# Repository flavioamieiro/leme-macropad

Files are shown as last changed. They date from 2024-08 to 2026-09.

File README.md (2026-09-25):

## Leme macropad

This is a macropad based on the RP2040 microcontroller meant to run QMK.

It currently is a handwired macropad using a raspberry Pi pico

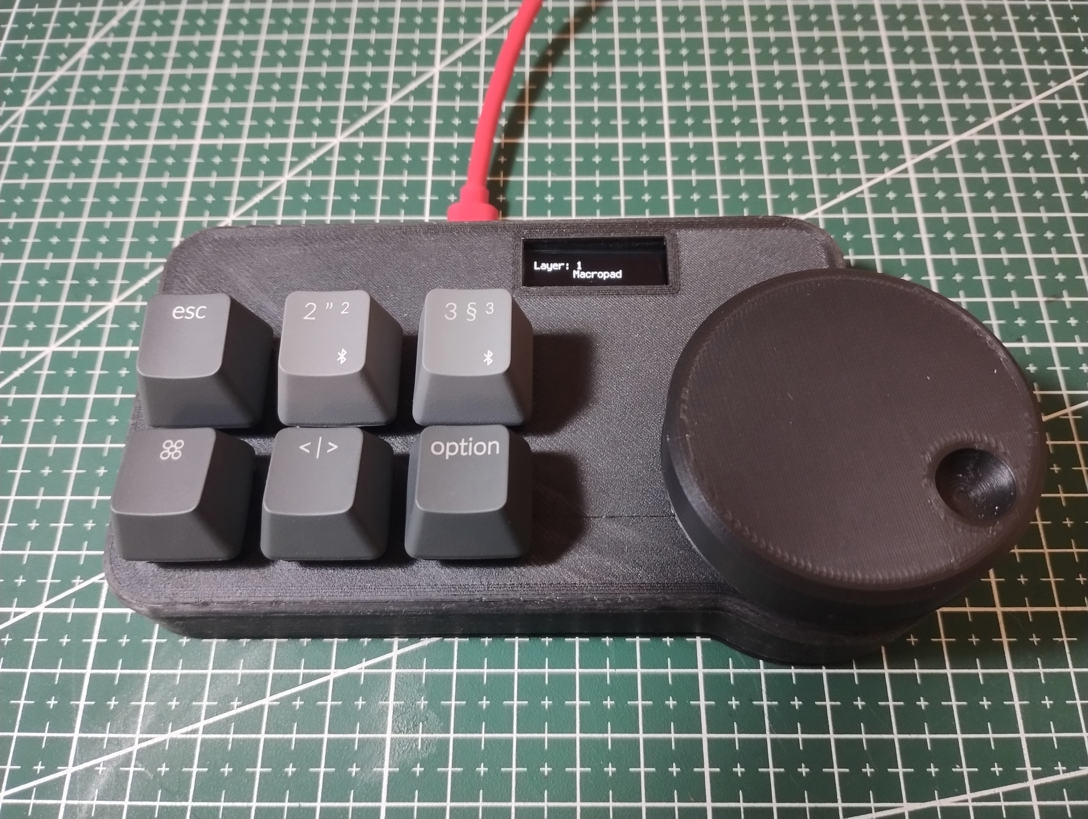
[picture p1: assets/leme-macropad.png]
leme macropad


The [README in the software directory](software/README.md) explains how to install QMK on a raspberry pi pico to support it.

The [leme_macropad](leme_macropad/) directory contains a first revision for custom hardware for it (which, unfortunately, currently doesn't work).

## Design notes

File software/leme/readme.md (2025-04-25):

# leme

leme

A simple macropad with six keys, a rotary encoder and a small screen

* Keyboard Maintainer: [Flávio Amieiro](https://github.com/flavioamieiro)
* Hardware Supported: Custom PCB released as open hardware
* Hardware Availability: https://github.com/flavioamieiro/leme-macropad

Make example for this keyboard (after setting up your build environment):

    make leme:default

Flashing example for this keyboard:

    make leme:default:flash

See the [build environment setup](https://docs.qmk.fm/#/getting_started_build_tools) and the [make instructions](https://docs.qmk.fm/#/getting_started_make_guide) for more information. Brand new to QMK? Start with our [Complete Newbs Guide](https://docs.qmk.fm/#/newbs).

## Bootloader

To enter the bootloader , hold down the top left key while you plug in the macropad.

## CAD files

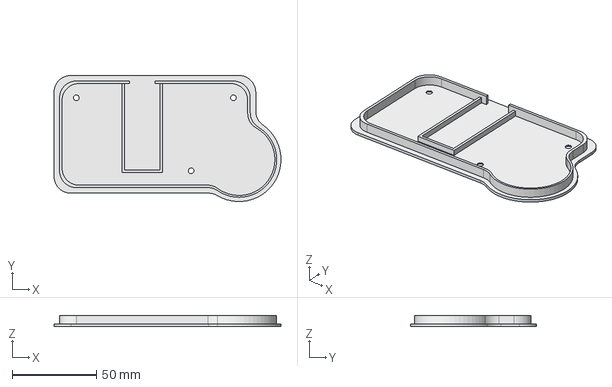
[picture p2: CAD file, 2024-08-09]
case/leme.FCStd
135.0 x 75.0 x 6.50 mm

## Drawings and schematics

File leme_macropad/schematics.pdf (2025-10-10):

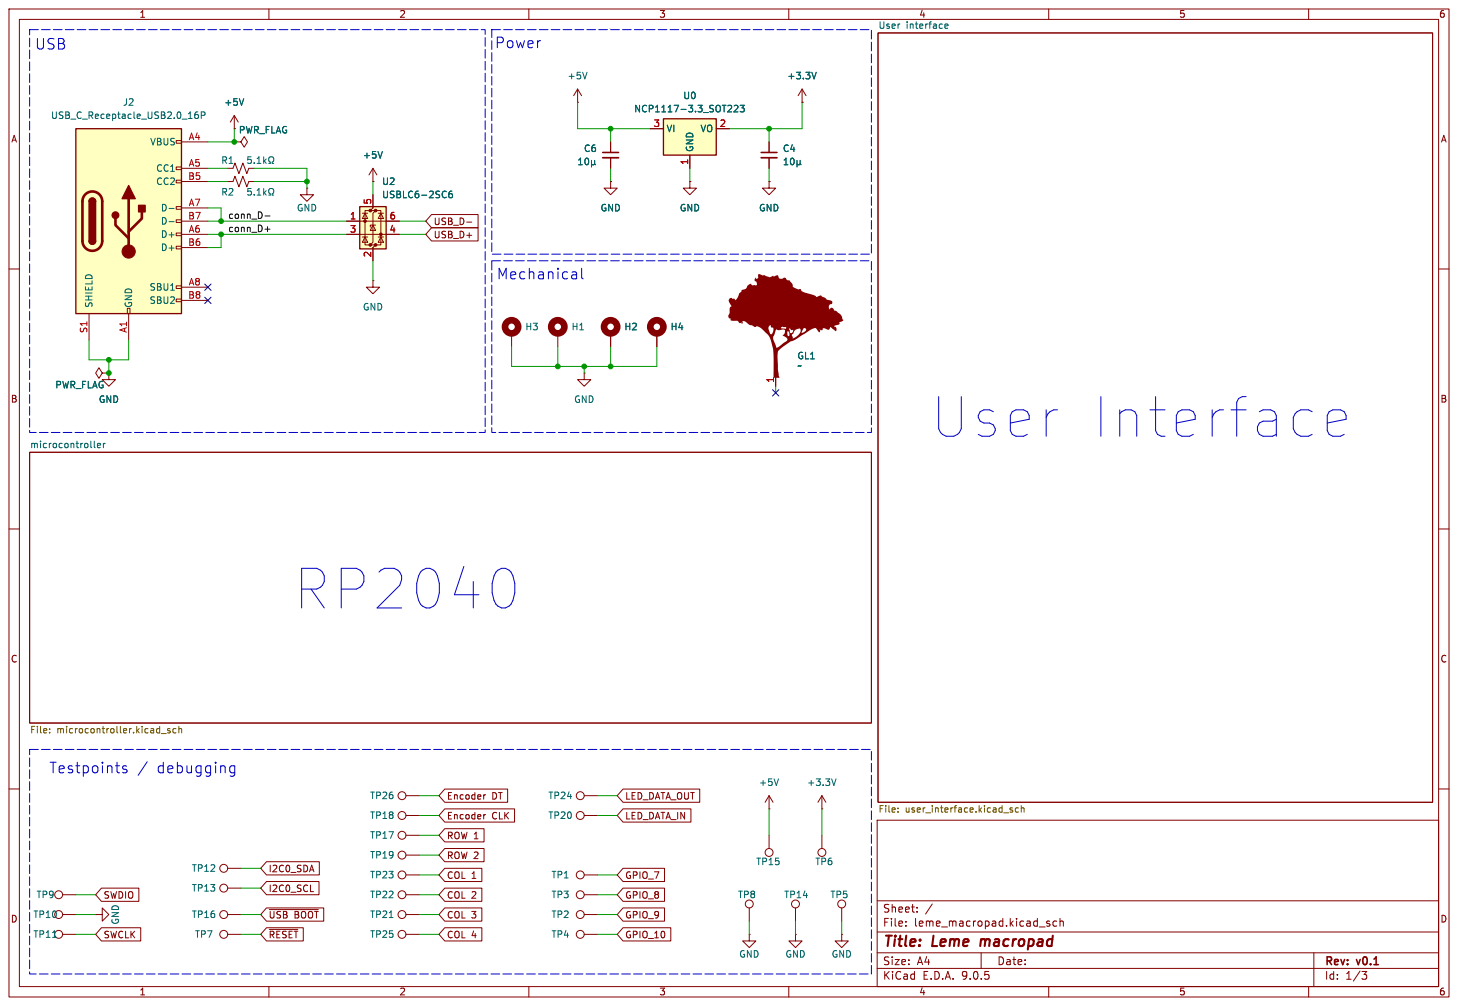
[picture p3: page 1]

File: leme_macropad.kicad_sch Sheet: / microcontroller File: microcontroller.kicad_sch

Id: 1/3 Title: Leme macropad

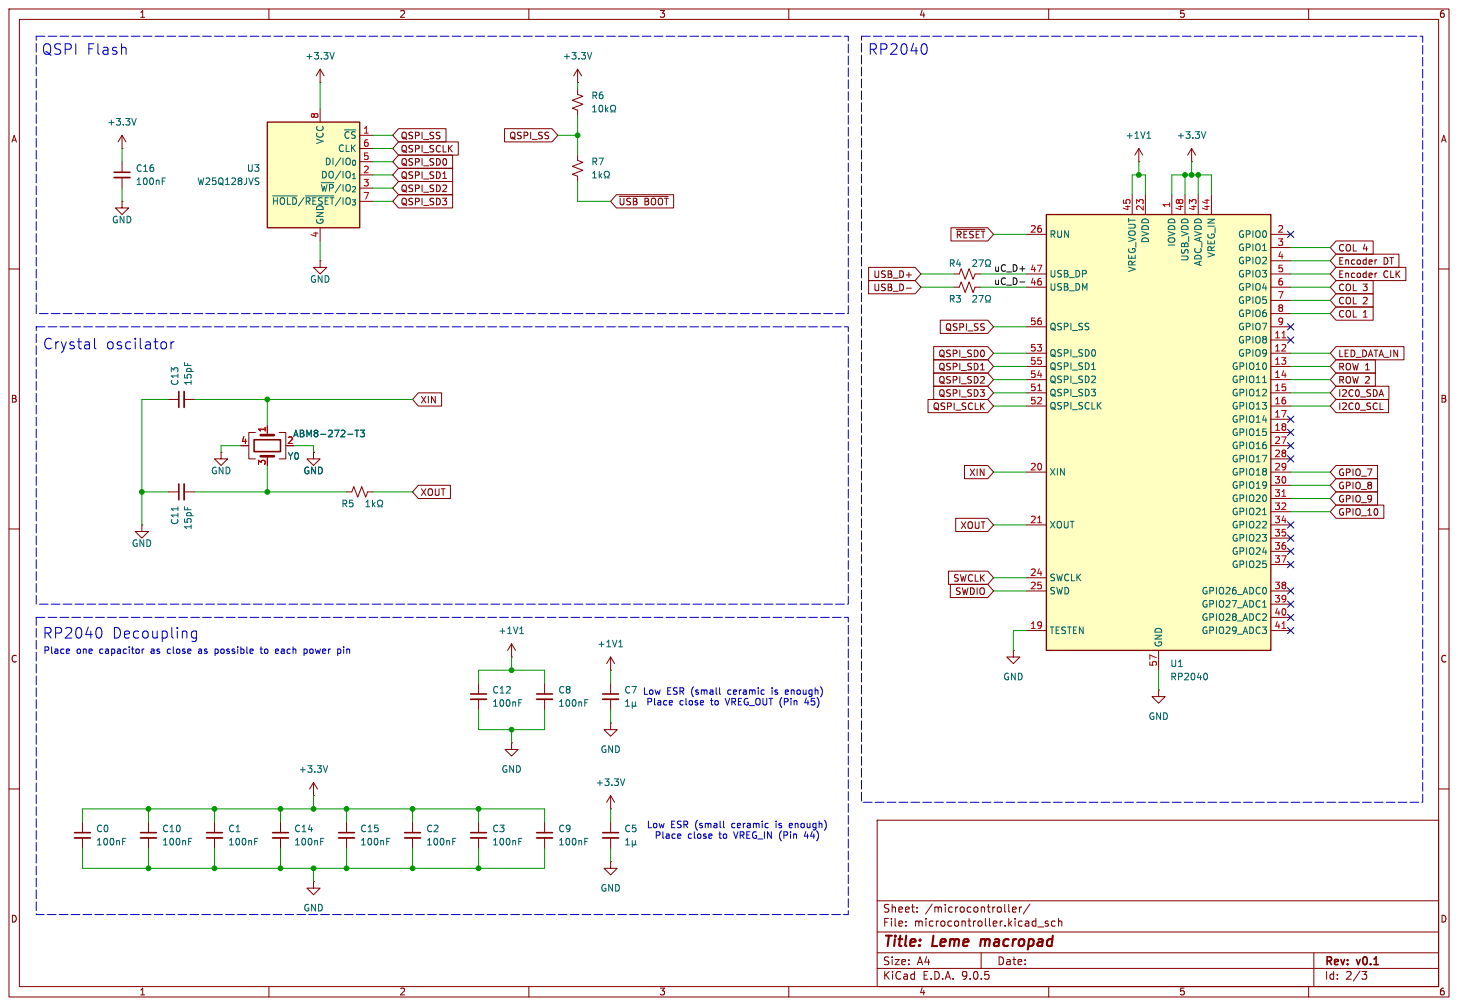
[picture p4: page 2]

File: microcontroller.kicad_sch Sheet: /microcontroller/
Id: 2/3 Title: Leme macropad

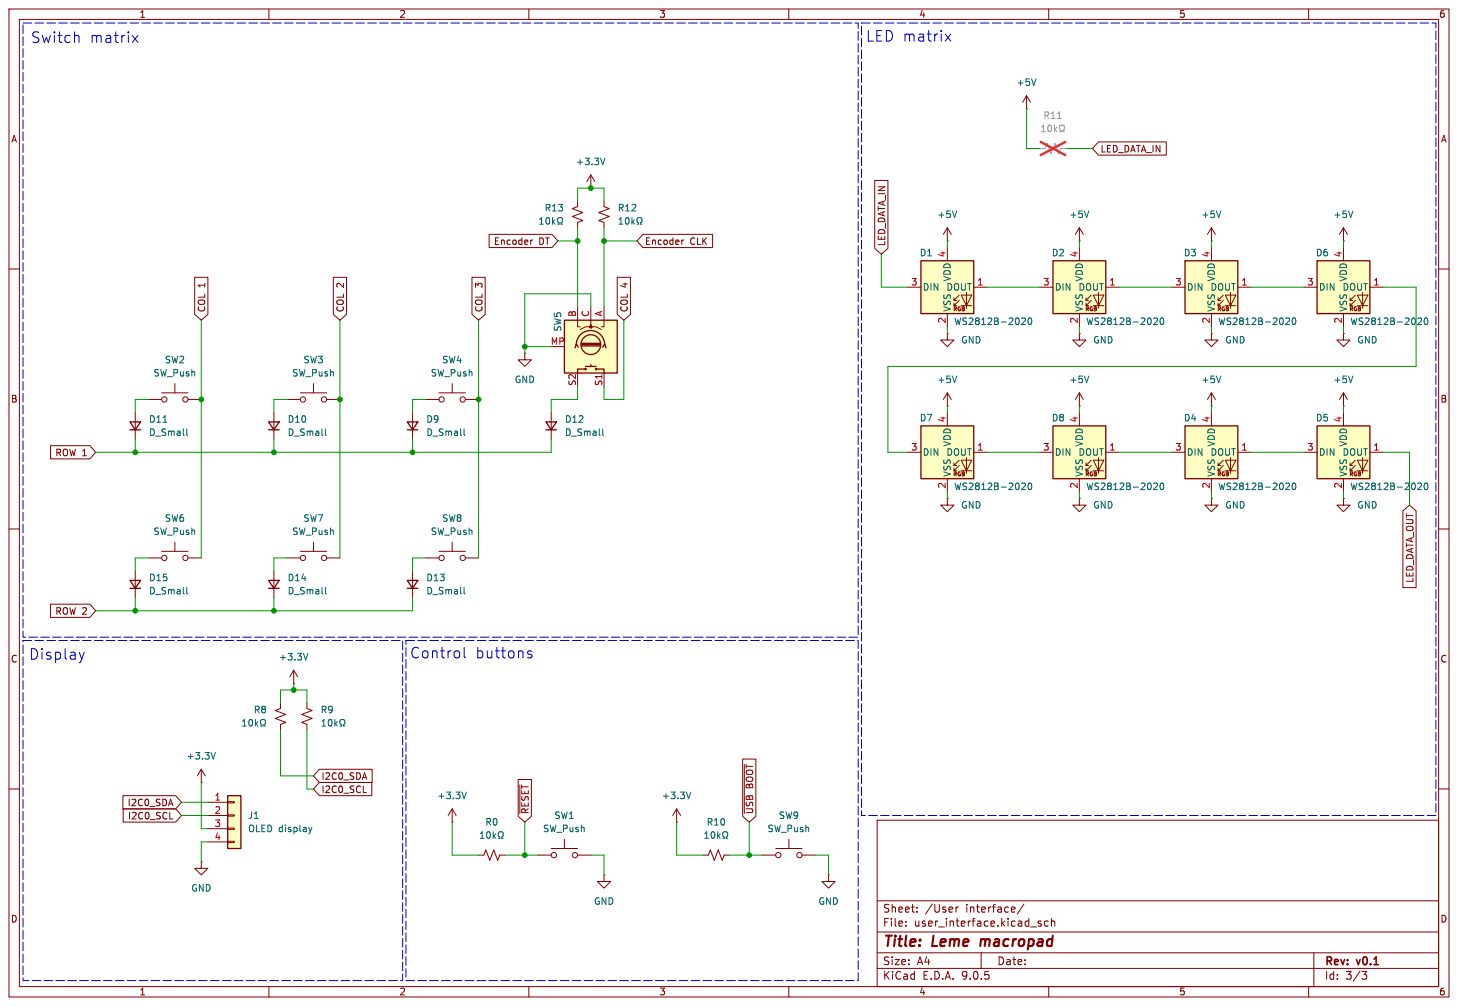
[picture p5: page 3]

File: user_interface.kicad_sch Sheet: /User interface/
Id: 3/3 Title: Leme macropad

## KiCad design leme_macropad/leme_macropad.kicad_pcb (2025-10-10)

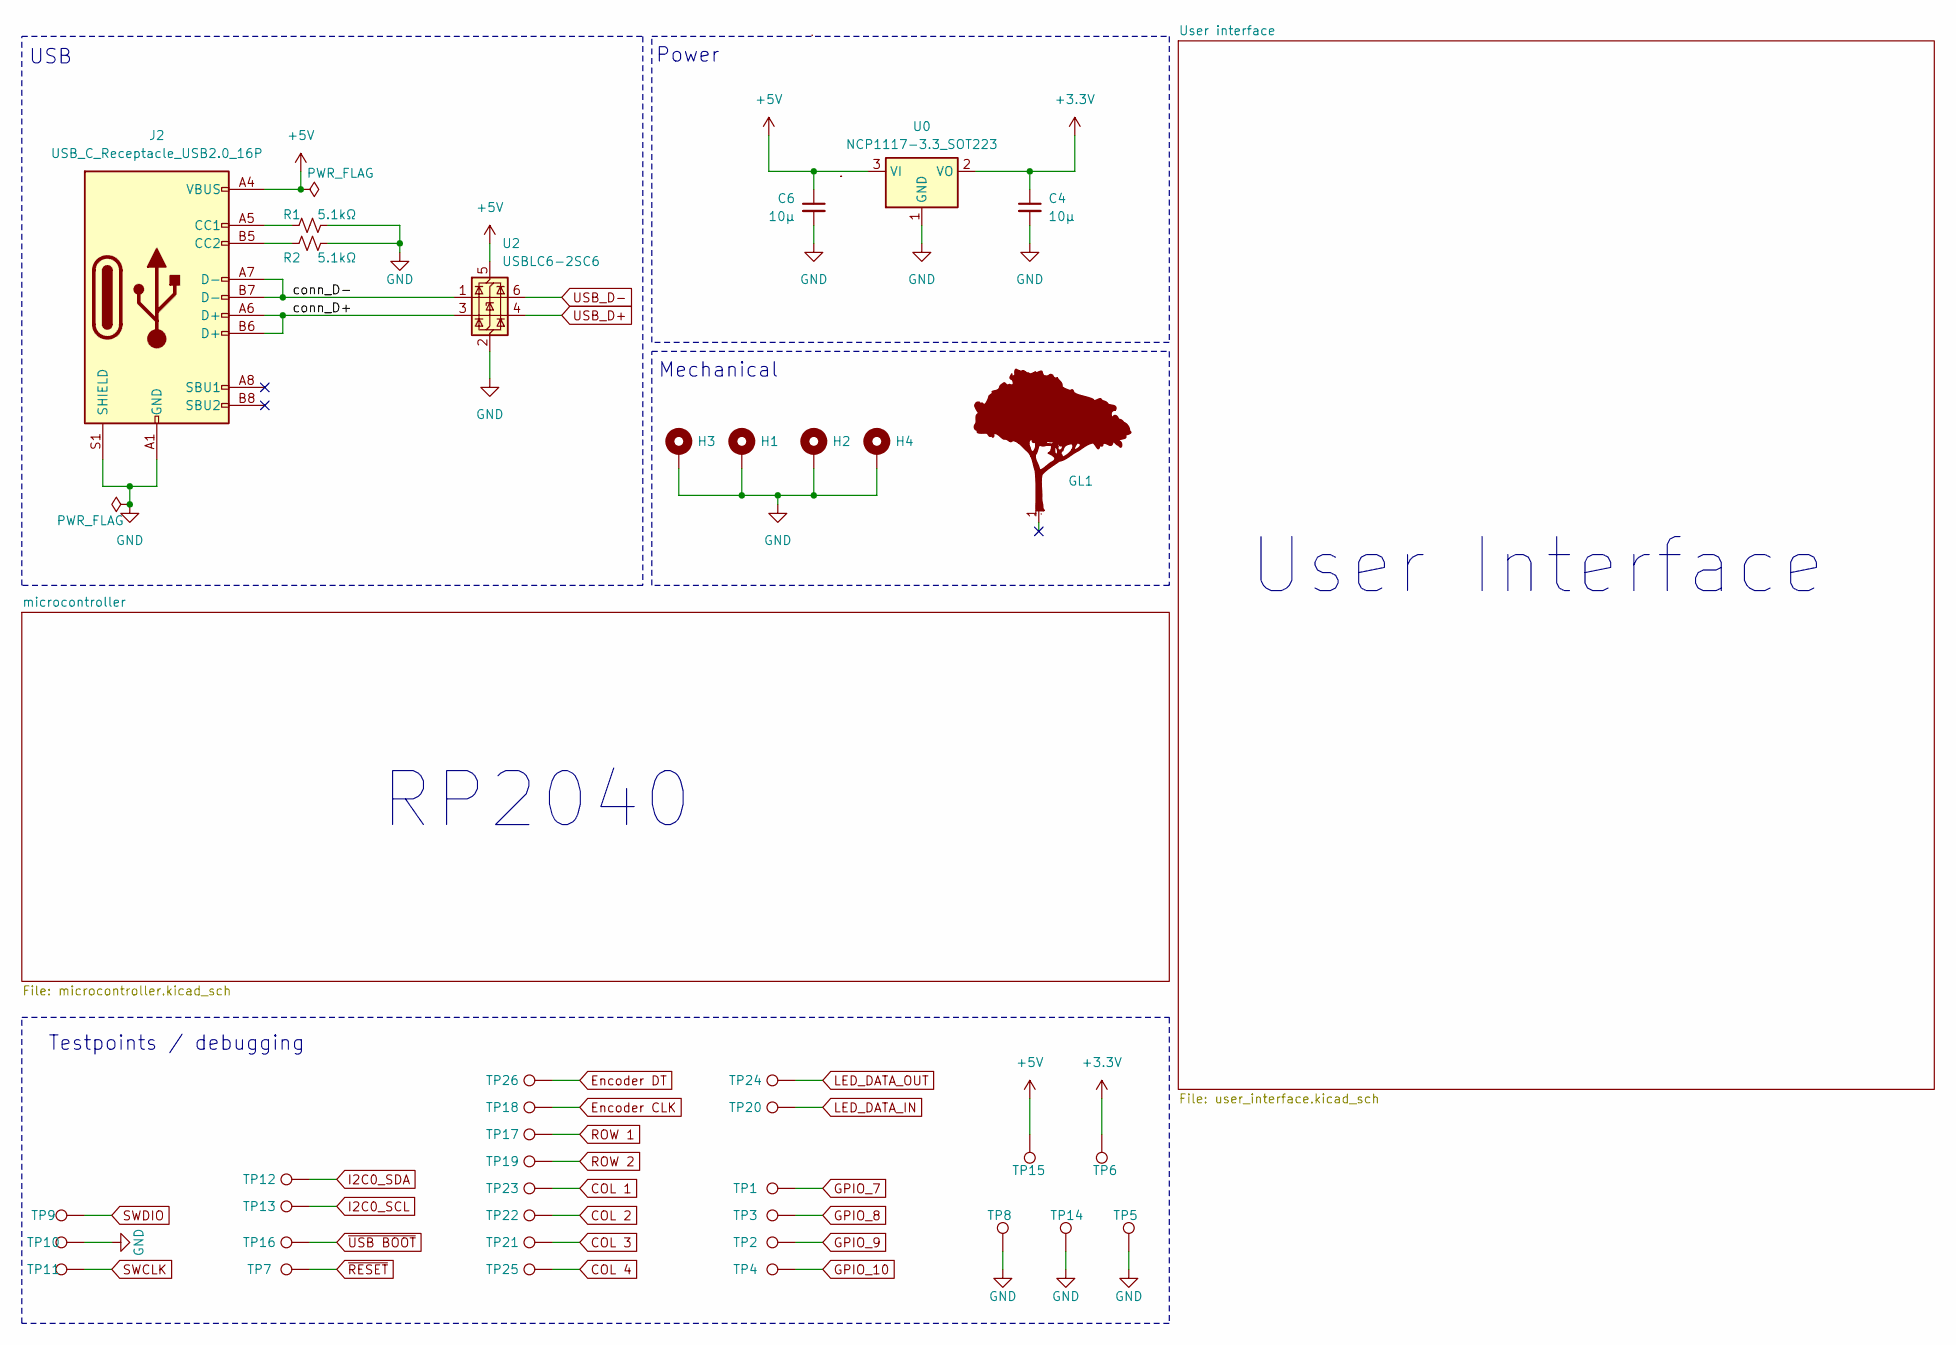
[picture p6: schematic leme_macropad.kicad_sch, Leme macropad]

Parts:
C4, C6: 10μ; C_0402_1005Metric_Pad0.74x0.62mm_HandSolder
GL1: ipe_logo
H1, H2, H3, H4: MountingHole_Pad; MountingHole_2.2mm_M2_Pad
J2: USB_C_Receptacle_USB2.0_16P; USB_C_Receptacle_GCT_USB4105-xx-A_16P_TopMnt_Horizontal
R1, R2: 5.1kΩ; R_0402_1005Metric_Pad0.72x0.64mm_HandSolder
TP1, TP2, TP3, TP4, TP5, TP6, TP7, TP8, TP9, TP10, TP11, TP12, TP13, TP14, TP15, TP16, TP17, TP18, TP19, TP20, TP21, TP22, TP23, TP24, TP25, TP26: TestPoint; TestPoint_Pad_D1.0mm
U0: NCP1117-3.3_SOT223; SOT-223-3_TabPin2
U2: USBLC6-2SC6; SOT-23-6

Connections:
+3.3V: C4.1, TP6.1, U0.2 (VO); also elsewhere on the board
+5V: C6.1, J2.A4 (VBUS), J2.A9 (VBUS), J2.B4 (VBUS), J2.B9 (VBUS), TP15.1, U0.3 (VI), U2.5 (VBUS); also elsewhere on the board
/conn_D+: J2.A6 (D+), J2.B6 (D+), U2.3 (I/O2)
/conn_D-: J2.A7 (D-), J2.B7 (D-), U2.1 (I/O1)
COL 1: TP23.1; also elsewhere on the board
COL 2: TP22.1; also elsewhere on the board
COL 3: TP21.1; also elsewhere on the board
COL 4: TP25.1; also elsewhere on the board
Encoder CLK: TP18.1; also elsewhere on the board
Encoder DT: TP26.1; also elsewhere on the board
GND: C4.2, C6.2, H1.1, H2.1, H3.1, H4.1, J2.A1 (GND), J2.A12 (GND), J2.B1 (GND), J2.B12 (GND), J2.S1 (SHIELD), R1.2, R2.2, TP5.1, TP8.1, TP10.1, TP14.1, U0.1 (GND), U2.2 (GND); also elsewhere on the board
GPIO_7: TP1.1; also elsewhere on the board
GPIO_8: TP3.1; also elsewhere on the board
GPIO_9: TP2.1; also elsewhere on the board
GPIO_10: TP4.1; also elsewhere on the board
I2C0_SCL: TP13.1; also elsewhere on the board
I2C0_SDA: TP12.1; also elsewhere on the board
LED_DATA_IN: TP20.1; also elsewhere on the board
LED_DATA_OUT: TP24.1; also elsewhere on the board
unnamed: J2.A5 (CC1), R1.1
unnamed: J2.B5 (CC2), R2.1
ROW 1: TP17.1; also elsewhere on the board
ROW 2: TP19.1; also elsewhere on the board
SWCLK: TP11.1; also elsewhere on the board
SWDIO: TP9.1; also elsewhere on the board
USB_D+: U2.4 (I/O2); also elsewhere on the board
USB_D-: U2.6 (I/O1); also elsewhere on the board
~RESET: TP7.1; also elsewhere on the board
~USB BOOT: TP16.1; also elsewhere on the board

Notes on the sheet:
Mechanical
User Interface
USB
RP2040
Testpoints / debugging
Power

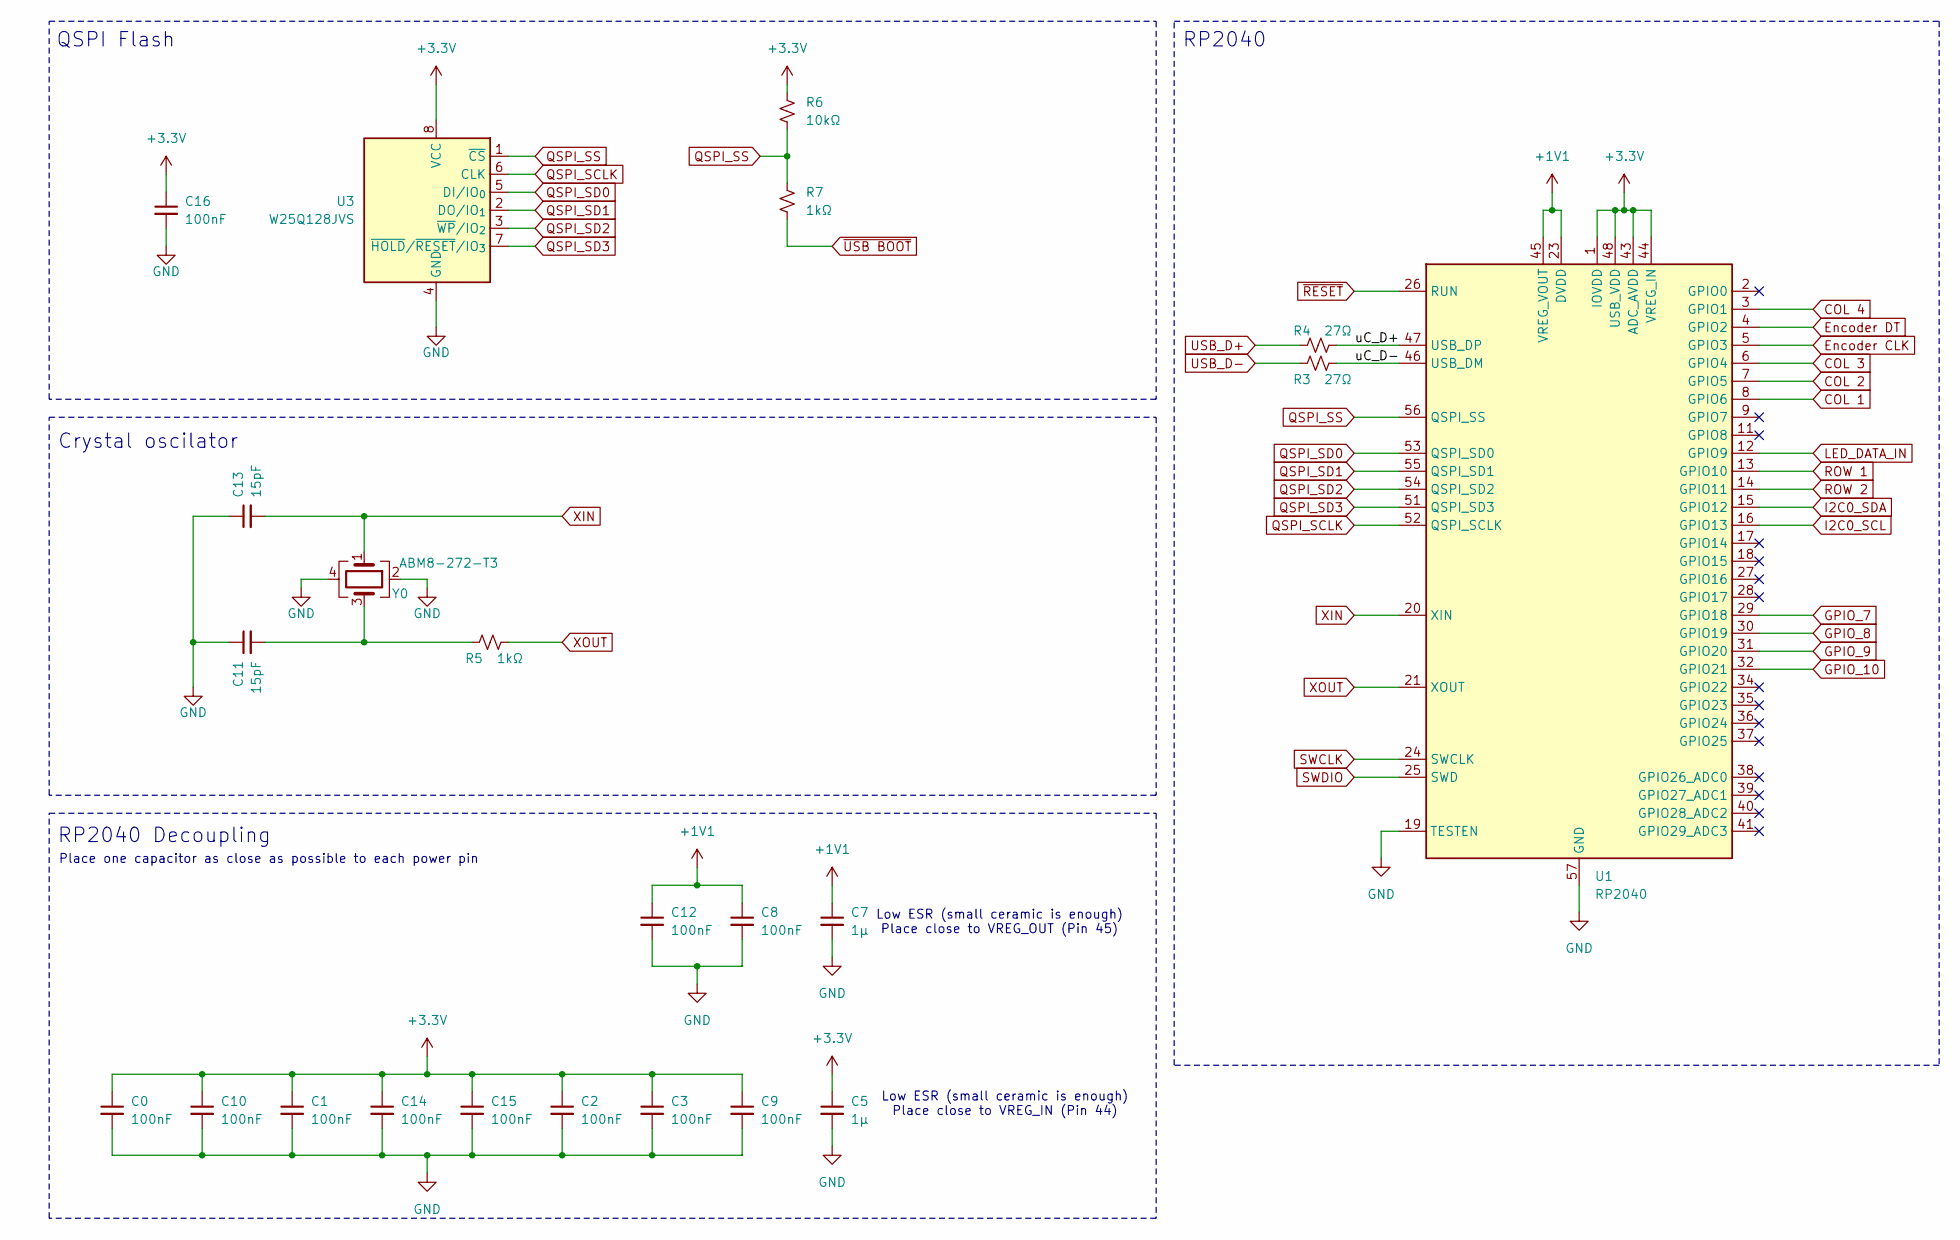
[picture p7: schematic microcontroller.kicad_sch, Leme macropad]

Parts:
C0, C1, C2, C3, C8, C9, C10, C12, C14, C15, C16: 100nF; C_0402_1005Metric_Pad0.74x0.62mm_HandSolder
C5, C7: 1μ; C_0402_1005Metric_Pad0.74x0.62mm_HandSolder
C11, C13: 15pF; C_0402_1005Metric_Pad0.74x0.62mm_HandSolder
R3, R4: 27Ω; R_0402_1005Metric_Pad0.72x0.64mm_HandSolder
R5, R7: 1kΩ; R_0402_1005Metric_Pad0.72x0.64mm_HandSolder
R6: 10kΩ; R_0402_1005Metric_Pad0.72x0.64mm_HandSolder
U1: RP2040; QFN-56-1EP_7x7mm_P0.4mm_EP3.2x3.2mm
U3: W25Q128JVS; SOIC-8_5.3x5.3mm_P1.27mm
Y0: ABM8-272-T3; Crystal_SMD_3225-4Pin_3.2x2.5mm

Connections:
+1V1: C7.1, C8.1, C12.1, U1.23 (DVDD), U1.45 (VREG_VOUT), U1.50 (DVDD)
+3.3V: C0.1, C1.1, C2.1, C3.1, C5.1, C9.1, C10.1, C14.1, C15.1, C16.1, R6.2, U1.1 (IOVDD), U1.10 (IOVDD), U1.22 (IOVDD), U1.33 (IOVDD), U1.42 (IOVDD), U1.43 (ADC_AVDD), U1.44 (VREG_IN), U1.48 (USB_VDD), U1.49 (IOVDD), U3.8 (VCC); also elsewhere on the board
/microcontroller/uC_D+: R4.2, U1.47 (USB_DP)
/microcontroller/uC_D-: R3.2, U1.46 (USB_DM)
COL 1: U1.8 (GPIO6); also elsewhere on the board
COL 2: U1.7 (GPIO5); also elsewhere on the board
COL 3: U1.6 (GPIO4); also elsewhere on the board
COL 4: U1.3 (GPIO1); also elsewhere on the board
Encoder CLK: U1.5 (GPIO3); also elsewhere on the board
Encoder DT: U1.4 (GPIO2); also elsewhere on the board
GND: C0.2, C1.2, C2.2, C3.2, C5.2, C7.2, C8.2, C9.2, C10.2, C11.1, C12.2, C13.1, C14.2, C15.2, C16.2, U1.19 (TESTEN), U1.57 (GND), U3.4 (GND), Y0.2, Y0.4; also elsewhere on the board
GPIO_7: U1.29 (GPIO18); also elsewhere on the board
GPIO_8: U1.30 (GPIO19); also elsewhere on the board
GPIO_9: U1.31 (GPIO20); also elsewhere on the board
GPIO_10: U1.32 (GPIO21); also elsewhere on the board
I2C0_SCL: U1.16 (GPIO13); also elsewhere on the board
I2C0_SDA: U1.15 (GPIO12); also elsewhere on the board
LED_DATA_IN: U1.12 (GPIO9); also elsewhere on the board
unnamed: C11.2, R5.1, Y0.3
QSPI_SCLK: U1.52 (QSPI_SCLK), U3.6 (CLK)
QSPI_SD0: U1.53 (QSPI_SD0), U3.5 (DI/IO_{0})
QSPI_SD1: U1.55 (QSPI_SD1), U3.2 (DO/IO_{1})
QSPI_SD2: U1.54 (QSPI_SD2), U3.3 (~WP/IO_{2})
QSPI_SD3: U1.51 (QSPI_SD3), U3.7 (~HOLD/~RESET/IO_{3})
QSPI_SS: R6.1, R7.2, U1.56 (QSPI_SS), U3.1 (~CS)
ROW 1: U1.13 (GPIO10); also elsewhere on the board
ROW 2: U1.14 (GPIO11); also elsewhere on the board
SWCLK: U1.24 (SWCLK); also elsewhere on the board
SWDIO: U1.25 (SWD); also elsewhere on the board
USB_D+: R4.1; also elsewhere on the board
USB_D-: R3.1; also elsewhere on the board
XIN: C13.2, U1.20 (XIN), Y0.1
XOUT: R5.2, U1.21 (XOUT)
~RESET: U1.26 (RUN); also elsewhere on the board
~USB BOOT: R7.1; also elsewhere on the board

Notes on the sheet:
RP2040 Decoupling
Place one capacitor as close as possible to each power pin
QSPI Flash
RP2040
Low ESR (small ceramic is enough) Place close to VREG_OUT (Pin 45)
Low ESR (small ceramic is enough) Place close to VREG_IN (Pin 44)
Crystal oscilator

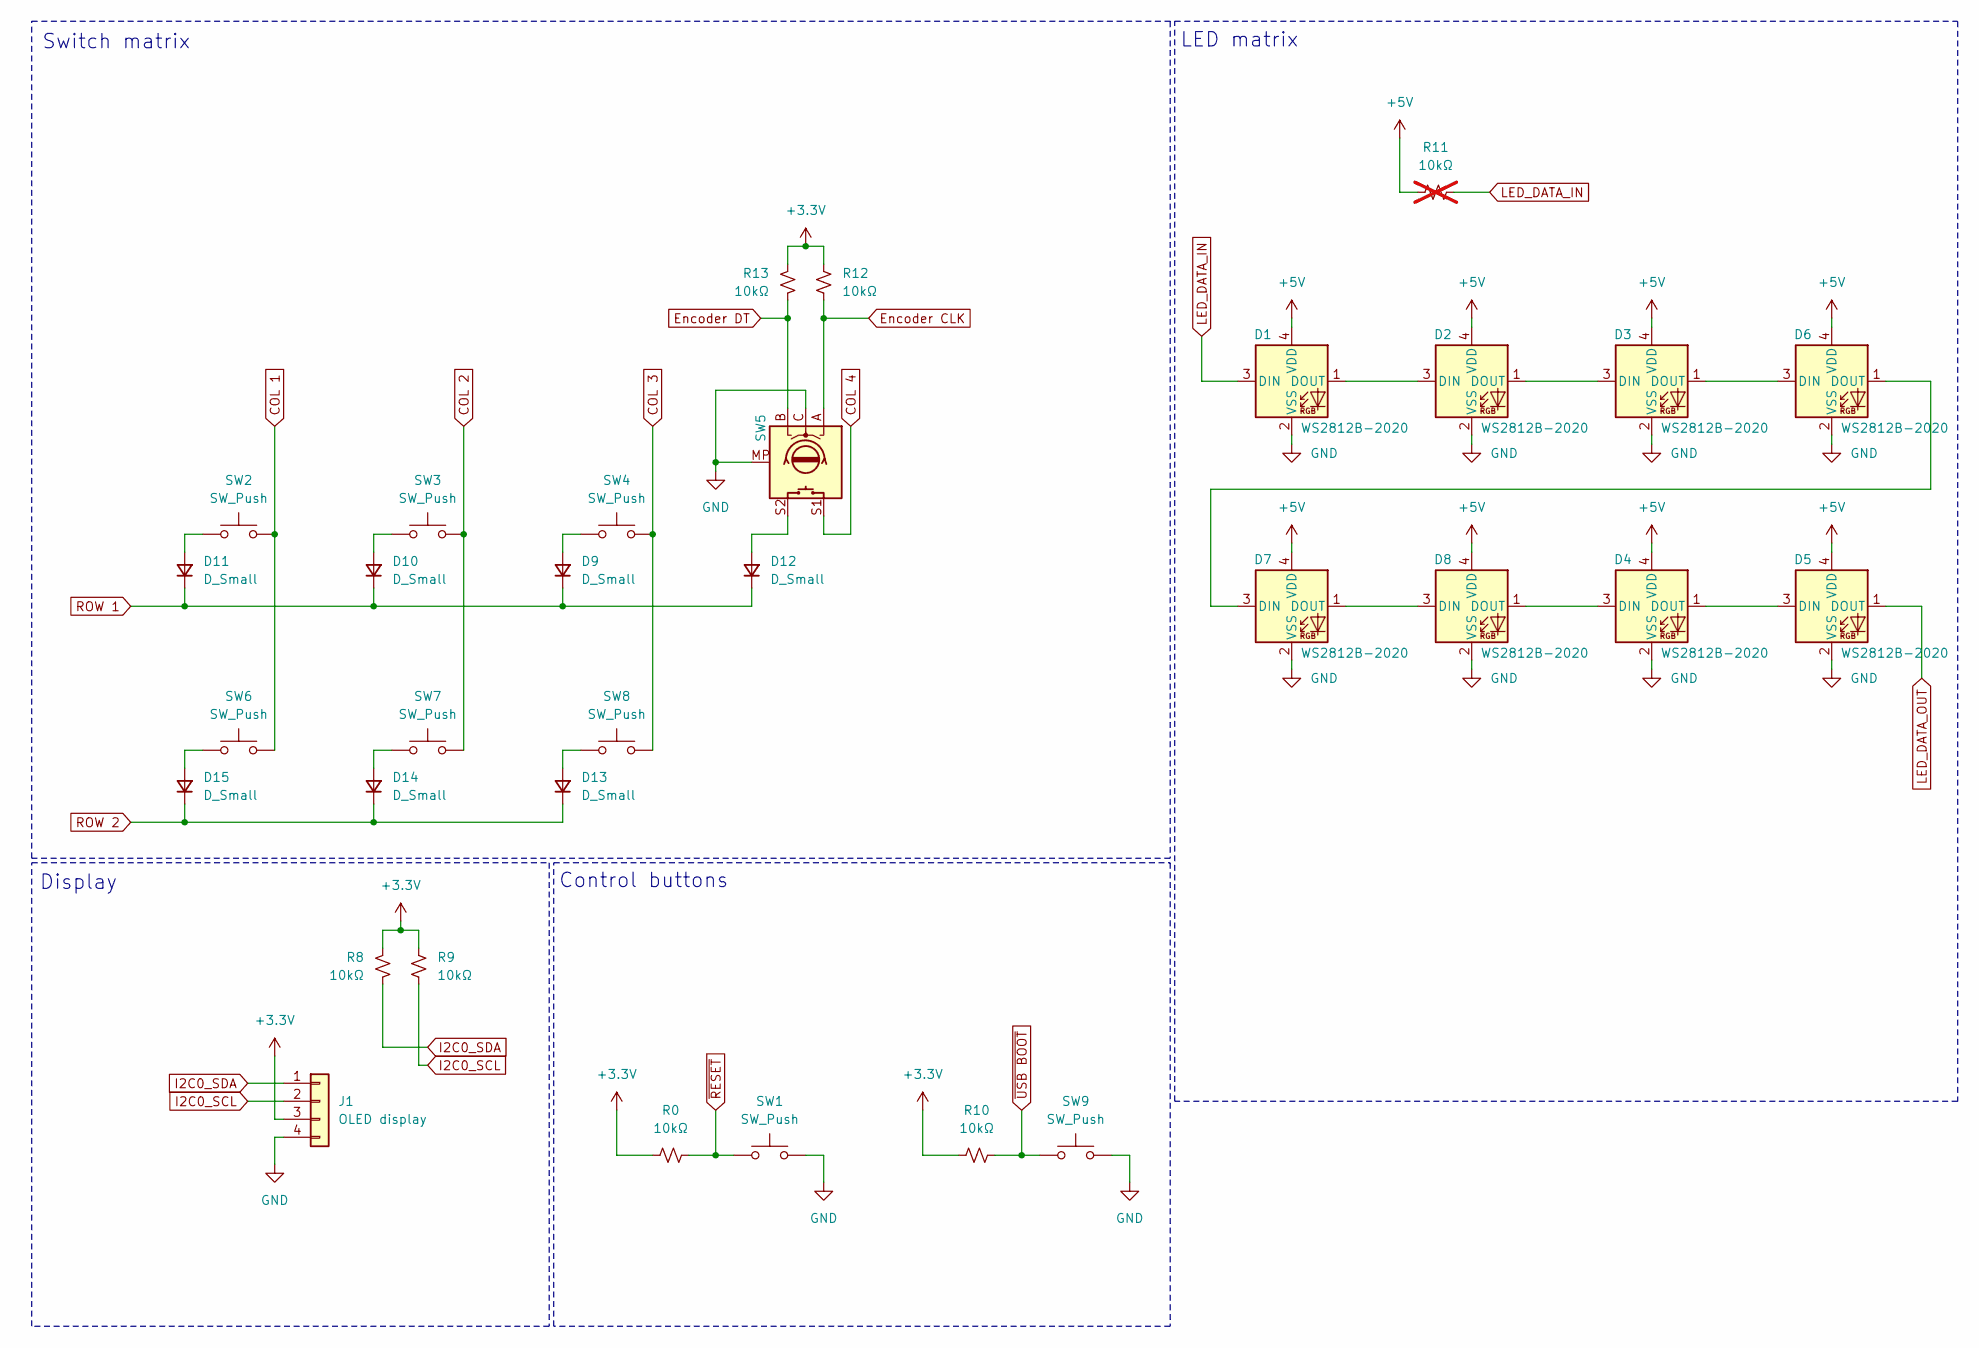
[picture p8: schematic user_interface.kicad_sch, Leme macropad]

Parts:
D1, D2, D3, D4, D5, D6, D7, D8: WS2812B-2020; LED_WS2812B-2020_PLCC4_2.0x2.0mm
D9, D10, D11, D12, D13, D14, D15: D_Small; D_SOD-123
J1: OLED display; PinHeader_1x04_P2.54mm_Vertical
R0, R8, R9, R10, R12, R13: 10kΩ; R_0402_1005Metric_Pad0.72x0.64mm_HandSolder
R11: 10kΩ; R_0402_1005Metric_Pad0.72x0.64mm_HandSolder; not fitted
SW1, SW9: SW_Push; CK_PTS636_SK43_SMTR_LFS
SW2, SW3, SW4, SW6, SW7, SW8: SW_Push; SW_Hotswap_Kailh_Choc_V1V2_1.00u
SW5: RotaryEncoder_Switch; RotaryEncoder_Alps_EC11E-Switch_Vertical_H20mm

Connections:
+3.3V: J1.3, R0.1, R8.2, R9.2, R10.1, R12.2, R13.2; also elsewhere on the board
+5V: D1.4 (VDD), D2.4 (VDD), D3.4 (VDD), D4.4 (VDD), D5.4 (VDD), D6.4 (VDD), D7.4 (VDD), D8.4 (VDD), R11.1; also elsewhere on the board
COL 1: SW2.2, SW6.2; also elsewhere on the board
COL 2: SW3.2, SW7.2; also elsewhere on the board
COL 3: SW4.2, SW8.2; also elsewhere on the board
COL 4: SW5.S1; also elsewhere on the board
Encoder CLK: R12.1, SW5.A; also elsewhere on the board
Encoder DT: R13.1, SW5.B; also elsewhere on the board
GND: D1.2 (VSS), D2.2 (VSS), D3.2 (VSS), D4.2 (VSS), D5.2 (VSS), D6.2 (VSS), D7.2 (VSS), D8.2 (VSS), J1.4, SW1.2, SW5.C, SW5.MP, SW9.2; also elsewhere on the board
I2C0_SCL: J1.2, R9.1; also elsewhere on the board
I2C0_SDA: J1.1, R8.1; also elsewhere on the board
LED_DATA_IN: D1.3 (DIN), R11.2; also elsewhere on the board
LED_DATA_OUT: D5.1 (DOUT); also elsewhere on the board
unnamed: D1.1 (DOUT), D2.3 (DIN)
unnamed: D2.1 (DOUT), D3.3 (DIN)
unnamed: D3.1 (DOUT), D6.3 (DIN)
unnamed: D4.3 (DIN), D8.1 (DOUT)
unnamed: D4.1 (DOUT), D5.3 (DIN)
unnamed: D6.1 (DOUT), D7.3 (DIN)
unnamed: D7.1 (DOUT), D8.3 (DIN)
unnamed: D9.2 (A), SW4.1
unnamed: D10.2 (A), SW3.1
unnamed: D11.2 (A), SW2.1
unnamed: D12.2 (A), SW5.S2
unnamed: D13.2 (A), SW8.1
unnamed: D14.2 (A), SW7.1
unnamed: D15.2 (A), SW6.1
ROW 1: D9.1 (K), D10.1 (K), D11.1 (K), D12.1 (K); also elsewhere on the board
ROW 2: D13.1 (K), D14.1 (K), D15.1 (K); also elsewhere on the board
~RESET: R0.2, SW1.1; also elsewhere on the board
~USB BOOT: R10.2, SW9.1; also elsewhere on the board

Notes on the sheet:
Control buttons
Switch matrix
LED matrix
Display

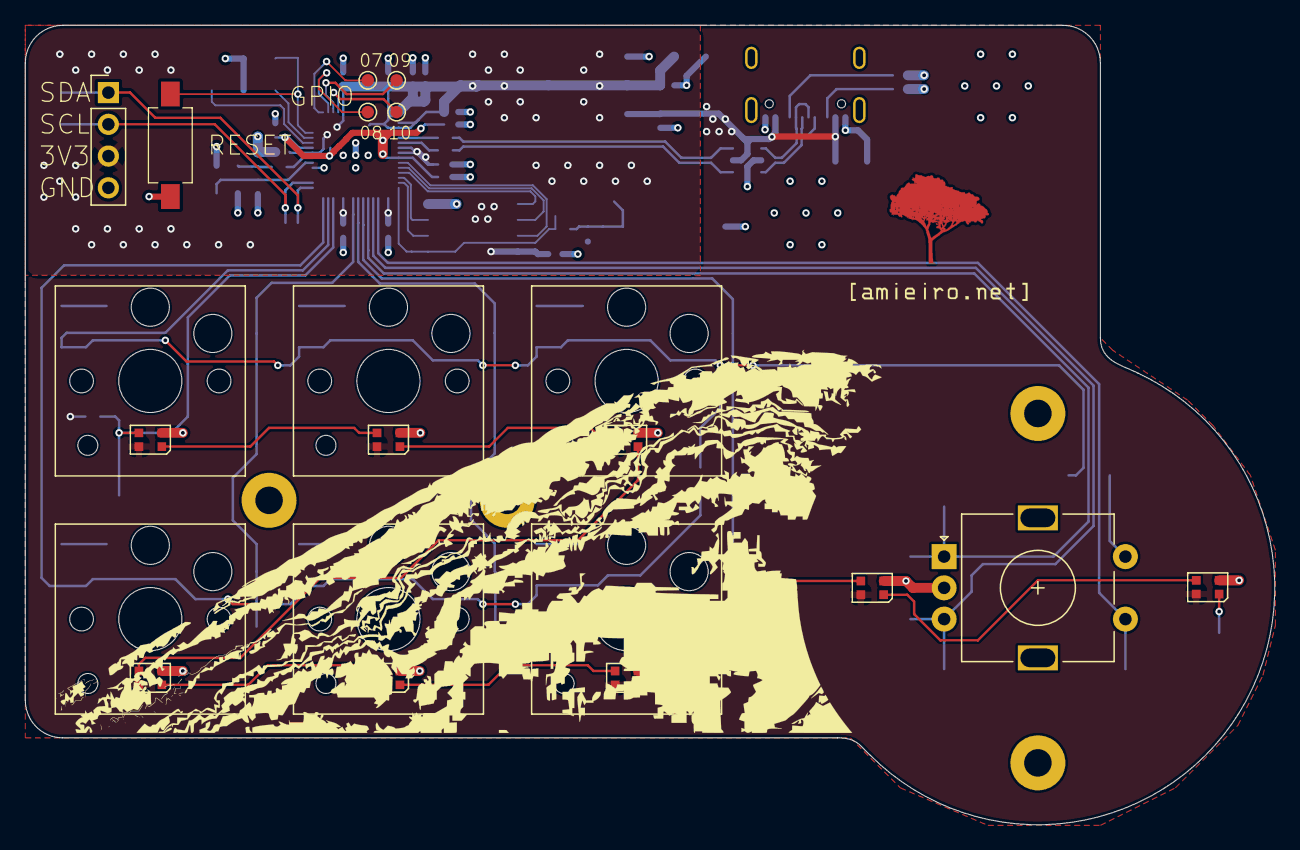
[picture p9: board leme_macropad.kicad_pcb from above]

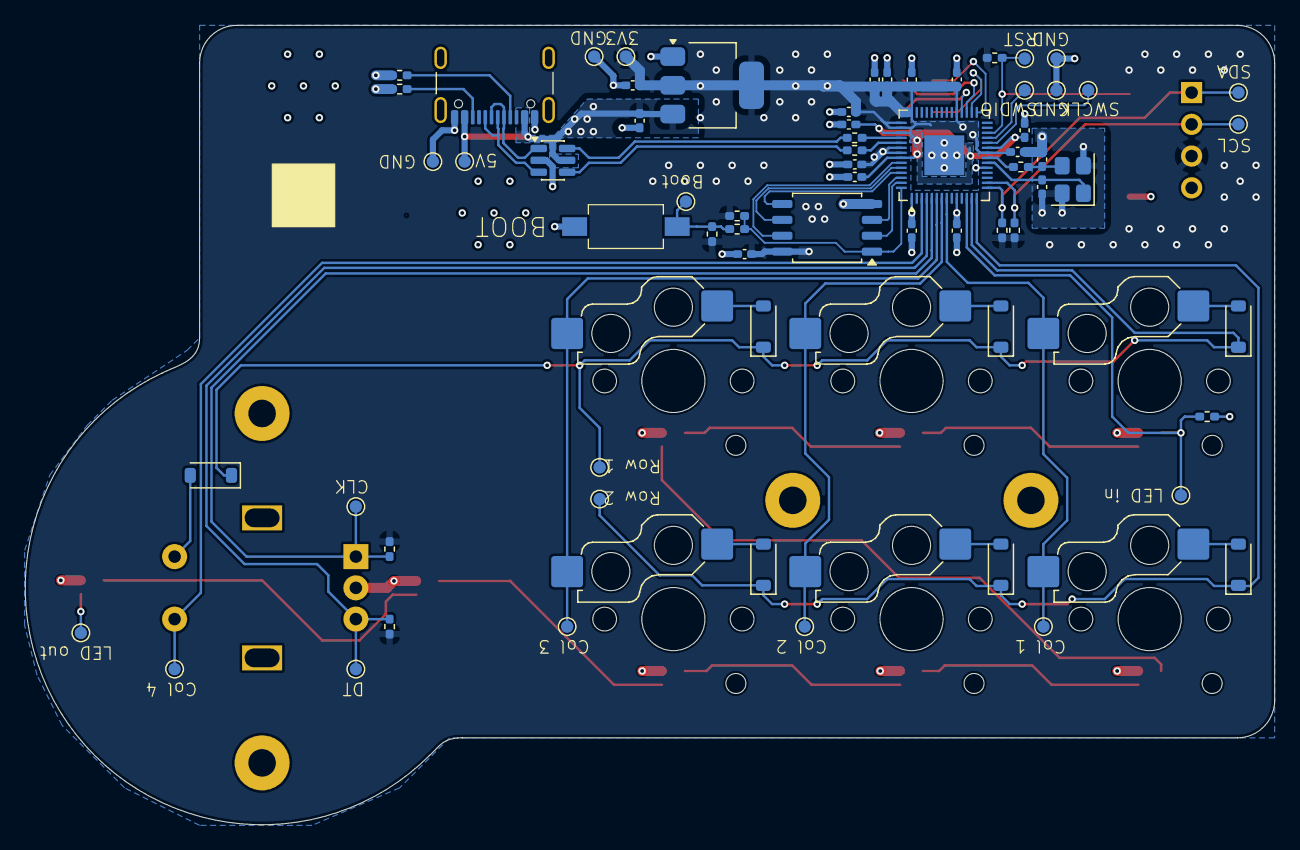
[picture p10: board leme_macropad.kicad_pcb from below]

Board: 4 copper layers, 99.9 x 63.9 mm, 94 parts (67 on the bottom side), 55 nets.

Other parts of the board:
Ref**: Val**; sea

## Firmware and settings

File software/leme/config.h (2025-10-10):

// Copyright 2025 Flavio Amieiro <amieiro.flavio@gmail.com>
// SPDX-License-Identifier: GPL-3.0-only
#pragma once

#define I2C_DRIVER I2CD0
#define I2C1_SDA_PIN GP12
#define I2C1_SCL_PIN GP13

#define OLED_SCROLL_TIMEOUT 10000
#define OLED_FADE_OUT TRUE
#define OLED_TIMEOUT 30000

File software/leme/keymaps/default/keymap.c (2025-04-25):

// Copyright 2025 Flavio Amieiro <amieiro.flavio@gmail.com>
// SPDX-License-Identifier: GPL-3.0-only

#include QMK_KEYBOARD_H

enum layers {
  _BASE,
  _NAVIGATION
};

const uint16_t PROGMEM keymaps[][MATRIX_ROWS][MATRIX_COLS] = {
    /*
     * ┌───┬───┬───┐
     * │ A │ B │ C │
     * ├───┼───┼───┤
     * │ D │ E │ F │
     * └───┴───┴───┘
     */
    [_BASE] = LAYOUT_ortho_2x3(
        KC_F14,    KC_F15,    KC_F16,
        KC_F17,    KC_F18,    TG(_NAVIGATION)
    ),
    [_NAVIGATION] = LAYOUT_ortho_2x3(
        _______, _______, _______,
        _______, QK_BOOT, TG(_NAVIGATION)
    )
};

#if defined(ENCODER_MAP_ENABLE)
const uint16_t PROGMEM encoder_map[][NUM_ENCODERS][NUM_DIRECTIONS] = {
  [_BASE] = { ENCODER_CCW_CW(KC_VOLD, KC_VOLU) },
  [_NAVIGATION] = { ENCODER_CCW_CW(MS_WHLU, MS_WHLD) }
};
#endif


#ifdef OLED_ENABLE

bool oled_task_user(void) {
    oled_write_P(PSTR("Layer: "), false);

    switch (get_highest_layer(layer_state)) {
        case _BASE:
            oled_write_ln_P(PSTR("Default"), false);
            break;
        case _NAVIGATION:
            oled_write_ln_P(PSTR("Navigation"), false);
            break;
        default:
            oled_write_ln_P(PSTR("Undefined"), false);
    }

    return false;
}
#endif

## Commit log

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2024-07-26 Adds start of schematics and update code for perfboard prototype
    This schematics is limited only to what is in the perfboard. The code
    now also reflects the way the perfboard is wired.
    [key-matrix.kicad_sch, macropad_hardware.kicad_pcb, macropad_hardware.kicad_sch]
2024-08-01 Adds Freecad project with a first case design
    This case design is meant to test the form factor. It doesn't fit the
    current electronics, since they were prototyped in a rather large
    perfboard. In it's current form, it can't be hardwired either, since
    there is no space for the Pi Pico inside.
    [macropad.FCStd]
2024-08-09 Finished first version of the case design
    This includes a bottom with a space for the raspberry pi pico.
    There are a few issues, mainly there's not enough space for all the
    wires (with JST connectors) I used in the prototype because one of the
    connectors hits the back of the display.
    [macropad.FCStd]
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2025-04-21 Renames project to `Leme`
    This includes renaming the Kicad and Freecad projects
    [key-matrix.kicad_sch, leme.FCStd, leme_hardware.kicad_pcb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]
2025-04-21 Changes firmware to use QMK instead of KMK
    This QMK firmware is still very limited in comparrison to what was
    available with KMK.
    * It still has only one layer
    * The rotary encoder pushbutton doesn't work yet
    * The display is not yet included
    [keymap.c]
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2025-04-21 Fixes copyright statement in keymaps.c
    [keymap.c]
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2025-04-24 Adds missing license header in config.h
    [config.h]
2025-04-24 Adds scrolling and fade out to OLED screen
    The scrolling helps avoid burn-in on the screen, and the fade out just
    looks better.
    This commit also decreases the time it takes to clear the screen.
    [config.h]
2025-04-24 Adds shortcut key in second layer to put the keyboard in bootloader mode
    This makes it much easier to test code, but should probably be removed
    later.
    [keymap.c]
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2025-05-16 Uses rotary encoder instead of module and includes switch in matrix
    The way QMK handles rotary encoder push buttons is to include it in the
    switch matrix, which means I needed to add another column. Since this
    opens space for an extra switch, I added it here, but it doesn't need to
    be a mechanical switch as the others. We can keep the same 3x2 layout of
    the main keys.
    Using the encoder instead of a module is the right way to go. The
    footprint for ALPS EC11E should be used when laying the PCB out because
    this seems to be by far the most common format and also matches the ones
    I have in stock.
    [leme_macropad.kicad_sch]
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2025-05-16 Replaces Pi pico with a RP2040
    This is much better for our purposes. It gives us more control, uses
    much less space on the PCB and allows us to use a USB-C connector.
    All the components around the RP2040 are the ones recommended in the
    RP2040 hardware design guide. They not only are recommended, but also
    readily available and easy enough to use.
    [leme_macropad.kicad_sch, microcontroller.kicad_sch]
2025-05-16 Annotates schematics again
    Everything changed a lot, so it makes sense to reorder the components.
    [leme_macropad.kicad_sch, microcontroller.kicad_sch]
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2025-05-23 Adds testpoints to some free GPIOs
    It doesn't hurt to have them broken out if we need it.
    [leme_macropad.kicad_sch, microcontroller.kicad_sch]
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2025-05-23 Assigns footprints to all components in schematics
    Passives are 0603, but if the layout gets too dificult (specially around
    the RP2040) we might want to decrease the size.
    The mechanical switches are set as hotswap sockets for Kailh v1/v2, but
    after routing everything we might want to do a version for MX switches.
    [leme_macropad.kicad_sch, microcontroller.kicad_sch, user_interface.kicad_sch]
2025-05-29 Adds M2 mounting holes to schematics
    The mounting holes are pads and connected to ground.
    [leme_macropad.kicad_sch]
2025-05-29 Adds logo to schematics
    This includes a symbol and a footprint. The logo is a pad, connected to
    ground.
    [leme_macropad.kicad_sch]
2025-05-29 Uses rotary encoder symbol with mounting pin
    The rotary switch we'll use has mounting pins that can be soldered.
    Since they're connected to the chassis, they're now connected to ground
    in the schematics.
    This change fixes a warning when importing the schematics to the PCB
    editor.
    [user_interface.kicad_sch]
2025-05-29 Moves logo footprint to the front copper layer
    We can always flip it in the board if we want. Being in the front is a
    better default.
    [leme_macropad.kicad_pcb]
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2025-05-29 Defines project defaults for PCB editor
    This includes pre-defined trace (and diff pair) widths, some DRC
    constraints and a 19.05mm grid to make it easier to position standard 1U
    switches.
    [leme_macropad.kicad_pcb]
2025-05-29 Adds drawing of knob with actual (outer) dimensions
    This will help trace the PCB edge. Even if the actual case changes
    quite, as expected, the overall shape and placement of the knob will
    probably be kept. The PCB should, obviously, be smaller then the outer
    radius of the knob, to account for case thickness.
    [leme_macropad.kicad_pcb]
2025-05-29 Adds edge cuts layer
    This was drawn based on a DXF exported from the bottom side of the
    current case.
    [leme_macropad.kicad_pcb]
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2025-05-29 Creates mechanical switch grouping with correct spacing between them
    The position is definitely not final, but at least they should be
    correct in relation to each other.
    [leme_macropad.kicad_pcb]
2025-05-30 Reduces PCB size to fit in the 100mmx100mm promotional price in JLCPCB
    The cost - including shipping and taxes - for the original dimensions
    would be too high, specially for a first revision. I might want to go
    back to the original dimensions later, but for now we'll keep it
    smaller, even at the expense of a bit of comfort in use.
    [leme_macropad.kicad_pcb]
2025-05-30 First placement of components the user interacts with
    This does not yet include the LEDs, though.
    [leme_macropad.kicad_pcb]
2025-05-30 Positions WS2812B-2020 LEDs under the LED window for the switches
    This results in a DRC violation for now, because the footprints don't
    have space in their courtyard for the LED.
    [leme_macropad.kicad_pcb]
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2025-06-27 Moves mounting point H2
    This should open more space for the layout of the microcontroller and
    everything else, while also hiding the only visible mounting whole and
    securing even more the rotary encoder.
    [leme_macropad.kicad_pcb]
2025-06-27 Removes SW8
    This button was there just to complete the matrix but we have no use for
    it. It would only make things harder to organize.
    [leme_macropad.kicad_pcb, user_interface.kicad_sch]
2025-06-30 First draft of the layout for the crystal oscillator
    This is not looking very good, but gives an idea of where the crystal
    should be. This might also be a good indication that we need to change
    the passives around the RP2040 to 0402, since 0603 are looking quite big
    right now.
    [leme_macropad.kicad_pcb]
2025-06-30 Changes resistors and capacitors to 0402
    This should make it much easier to route things and to comply with the
    signal integrity needs of some parts of the circuit.
    [leme_macropad.kicad_pcb, leme_macropad.kicad_sch, microcontroller.kicad_sch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]
2025-06-30 Reorganizes crystal oscillator after changing passives to 0402
    [leme_macropad.kicad_pcb]
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2025-06-30 Swaps USB pins on SRV05 to make routing easier
    [leme_macropad.kicad_pcb, leme_macropad.kicad_sch]
2025-09-19 Replaces SRV05 with USBLC6 for ESD protection
    The USBLC6 is not only built specifically to protect USB data lines, but
    is also cheaper than the SRV05.
    [leme_macropad.kicad_pcb, leme_macropad.kicad_sch, microcontroller.kicad_sch]
2025-09-19 Routes USB data lines
    Yeah, it's not good, but it is what it is for now.
    [leme_macropad.kicad_pcb]
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2025-09-22 Brings back inner GND planes
    For some reason they were deleted in the last commit.
    [leme_macropad.kicad_pcb]
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2025-09-24 Use smaller testpoint pads
    We have quite a few of them, and at 2mm it was impossible to space them
    0.1" apart.
    [leme_macropad.kicad_pcb, leme_macropad.kicad_sch]
2025-09-24 Routes the testpoints
    We're missing a few, but those will be removed.
    [leme_macropad.kicad_pcb]
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2025-09-24 Reassigns designators based on component location on the PCB
    Kicad 6 has a tool for that: geographical reannotate.
    [leme_macropad.kicad_pcb, leme_macropad.kicad_sch, microcontroller.kicad_sch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]
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2025-09-26 Deletes all tracks and vias to start from scratch
    This also removes the 3v3 and 5V planes.
    [leme_macropad.kicad_pcb]
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2025-09-26 Moves screw hole to open more space for routing
    This will also add more support to the buttons, albeit at the expense of
    losing some under de display connect. Because the display will likely
    not be connected and disconnected often, this should be ok.
    [leme_macropad.kicad_pcb]
2025-09-26 Routes RP2040 power
    This is basically a copy of the reference RP2040 design. Ground
    connections are still missing, even in the center pad, mainly because
    this footprint doesn't include vias.
    [leme_macropad.kicad_pcb]
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2025-09-26 Routes crystal oscillator
    [leme_macropad.kicad_pcb]
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2025-09-26 Moves USB connector to allow for more space for the power regulator
    The connector was in the midpoint of the board (considering the
    right-most part of the knob). Now it's a bit offset to the right.
    This is less than ideal, but will make life much easier.
    [leme_macropad.kicad_pcb]
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2025-09-26 Routes SWD debug signals and reset
    This required moving the decoupling capacitor for 1.1v.
    [leme_macropad.kicad_pcb]
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2025-09-29 Adds i2c pull-up resistors that were missing (!)
    [leme_macropad.kicad_pcb, microcontroller.kicad_sch]
2025-09-30 Moves SDA/SCL i2c pins to make it easier to route
    This also required moving the encoder pins, which will also make them
    easier to route with this placement of the RP2040.
    This commit also changes the configuration for QMK to use the new pins.
    [leme_macropad.kicad_pcb, microcontroller.kicad_sch, user_interface.kicad_sch]
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2025-10-03 Routes last missing items
    [leme_macropad.kicad_pcb]
2025-10-03 Fixes placement of the logo designator on schematics
    [leme_macropad.kicad_sch]
2025-10-03 Adds pull-up resistor footprint (component marked as DNP) to the LED data line
    QMK has a open-drain WS2812 driver[1], which we can potentially use to
    drive the LEDs at 5V. The issue is that, in theory, the RP2040 is not 5V
    tolerant, and the QMK docs are very specific about this needing to be
    the case. That's why the component is marked as "Do Not Populate", and
    we'll leave the footprint there for experimentation.
    [1]: https://docs.qmk.fm/drivers/ws2812#open-drain-circuit
    [leme_macropad.kicad_pcb, user_interface.kicad_sch]
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2025-10-05 Adds some missing labels
    [leme_macropad.kicad_pcb]
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2025-10-06 Excludes DRC violations for LEDs under Switches
    These LEDs will not be populated at first and the switches actually have
    enough space for them, but the footprint I'm using doesn't allow for
    this space in it's courtyard rules.
    [leme_macropad.kicad_pcb]
2025-10-06 Excludes DRC violations for GCT USB4105 connector
    This error is in the Kicad PCB itself, and I've used this connector with
    the same footprint in other boards with no issues.
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2025-10-09 Updates PCBs from library
    They started triggering DRC errors, probably because of kicad symbols
    update.
    [leme_macropad.kicad_pcb]
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
